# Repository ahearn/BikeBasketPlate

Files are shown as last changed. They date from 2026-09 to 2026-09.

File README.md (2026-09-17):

# Bike Basket Adapter Plate

OpenSCAD model of the basket-side mounting plate for a Bontrager Interchange
handlebar basket. This is the plate that screws to the basket and clips onto
the bracket on the bike.

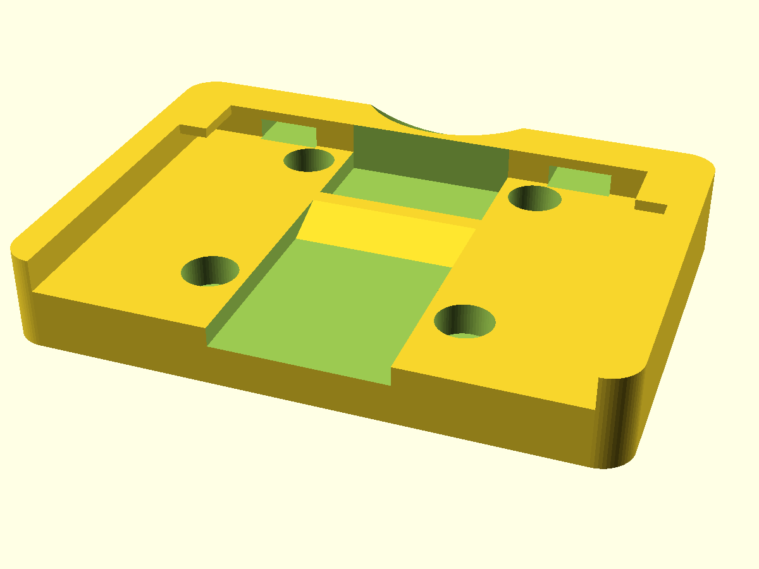
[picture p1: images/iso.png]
Isometric view


## What it fits

The [Bontrager Interchange Handlebar
Basket](https://www.trekbikes.com/us/en_US/equipment/bike-accessories/bike-baskets/bontrager-interchange-handlebar-basket/p/25614/).
The bike-side bracket carries Japanese and German patent numbers, a Sunny Wheel
Industrial licence notice and a 5 kg rating, so baskets sold under other brands
on the same licensed mount may use this geometry too.

This replaces the basket plate only. The bracket on the bike and its spring
lever need to be intact.

Dimensions came off one plate. Check them against yours before printing.

## How it mounts

Four countersunk screws hold the plate to the basket. The basket then drops
onto the bike-side bracket: the bracket's tongue slides into the slot between
the wings and the plate floor, guided by the central channel, and the spring
lever rides up the ramped latch and drops in behind it.

To release, press the lever through the scoop in the top wall.

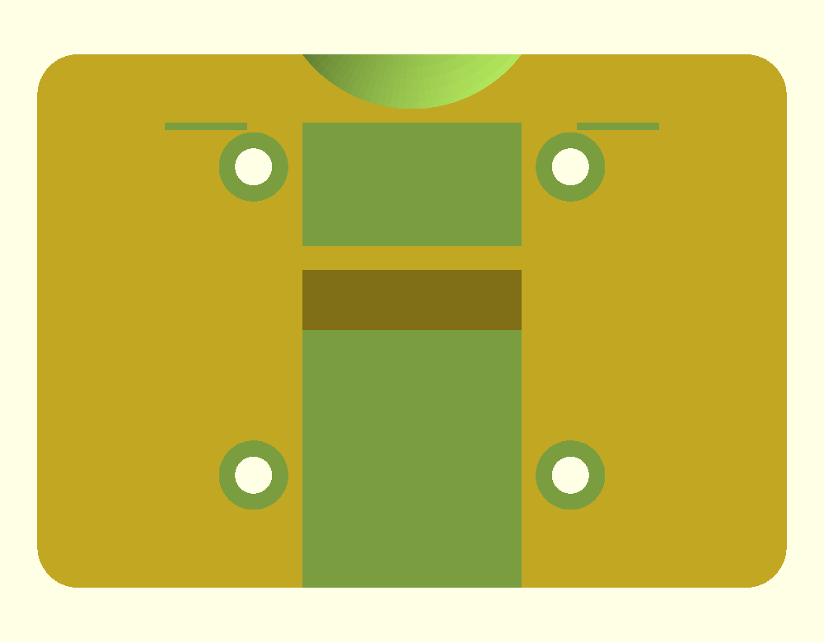
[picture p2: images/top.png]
Top view


## Dimensions

Heights are measured from the flat underside.

| Feature | Value |
|---|---|
| Overall | 109 × 77.7 mm |
| Main surface (screw-hole floor) | 11 mm |
| Channel floor | 7.4 mm |
| Perimeter wall / wing tops | 17 mm |
| Central channel width | 32 mm |
| Channel edge to side wall | 32.5 mm each side |
| Screw holes | 10.1 mm counterbore, 5.4 mm shaft, through |
| Screw hole centres | 46.1 mm across × 44.9 mm down |
| Latch | 8.8 mm ramp + 3.4 mm flat, top flush at 11 mm |
| Latch position | catch face 18 mm from the top wall |
| Wings | 21.6 mm long, 5.8 mm overhang, 2 mm thick |

The original plate is 105 mm wide. This one is 109 mm, which puts 2 mm of
clearance on each side wall and wing. Set `wall_relief = 0` for the original
width.

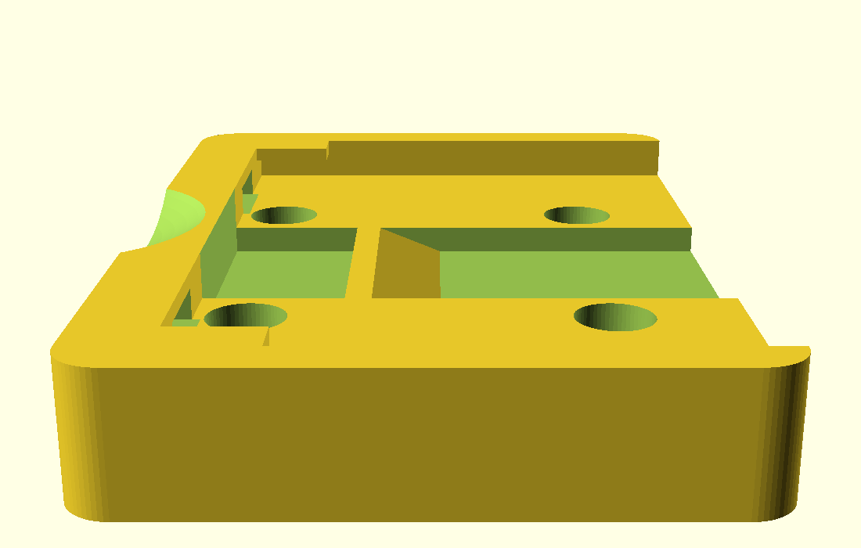
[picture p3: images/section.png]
Half section through the channel


## Building

Needs [OpenSCAD](https://openscad.org/). A built `basket_adapter_plate.stl` is
included. To regenerate it:

```
openscad -o basket_adapter_plate.stl basket_adapter_plate.scad
```

Every dimension is a named parameter at the top of the .scad file. A few are
marked `not measured` in the source — corner radius, top wall width, finger
scoop — and none of them affect how the plate latches.

## Printing

Print flat on the underside.

The wings cantilever 5.8 mm over a 4 mm gap and need support. The slots through
the top wall bridge 12 mm and print fine without.

PLA is fine for checking fit. Use PETG or ABS for something you'll actually
ride with. The mount is rated for 5 kg, and a printed plate won't match the
moulded original, so leave some margin.

## License

MIT

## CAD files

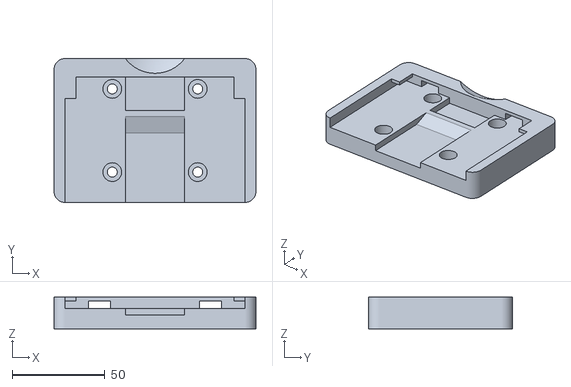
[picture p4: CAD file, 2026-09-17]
basket_adapter_plate.stl
109.0 x 77.7 x 17.0

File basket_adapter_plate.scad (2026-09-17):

// Basket adapter plate — bolts to the basket (4 screws), clips onto the
// bike-mounted bracket. Center channel carries a door-catch style latch bump;
// hook tabs on the side rims engage the bracket.
//
// All Z heights are absolute, measured from the flat underside of the part.

// ---- Overall plate ----
plate_w_nominal = 105;   // as measured on the original
wall_relief     = 2.0;   // side walls pushed out for fit; wings follow them
plate_w  = plate_w_nominal + 2 * wall_relief;
plate_h  = 77.7;
corner_r = 6;      // not measured

// ---- Z datums (underside = 0) ----
main_surface_z  = 11;    // flat area around the screw holes
channel_floor_z = 7.4;   // recessed groove floor
rim_z           = 17;    // top of raised perimeter wall
latch_top_z     = 11;    // flush with main surface
tab_top_z       = 17;    // flush with rim

// ---- Center channel (open through the bottom edge) ----
channel_w = 32;

// ---- Perimeter rim (top, left, right only — bottom edge is open) ----
channel_to_wall = 30.5 + wall_relief;  // measured 30.5, plus the fit relief
rim_w_side = plate_w / 2 - channel_w / 2 - channel_to_wall;
rim_w_top  = 10;         // not measured

// ---- Latch bump: ramp faces the bottom edge so the lever rides up it ----
latch_ramp_run = 8.8;   // slope run along the channel
latch_flat_run = 3.4;   // flat top run along the channel
latch_w        = channel_w;
latch_to_top_wall = 18;  // catch face to the top wall's inner face

// ---- Screw holes (countersunk, through) ----
cbore_d     = 10.1;
cbore_depth = 5.8;
shaft_d     = 5.4;
screw_h_gap = 36;      // edge-to-edge
screw_v_gap = 34.8;    // edge-to-edge
screw_h_pitch = screw_h_gap + cbore_d;  // gaps were measured between counterbore rims
screw_v_pitch = screw_v_gap + cbore_d;

// ---- Hook wings: overhang inward off the side rims, forming a slot with the
//      main surface that the bike bracket's tongue slides into ----
tab_len       = 21.6;  // along the side edge, starting at the top edge
tab_overhang  = 5.8;   // inward past the rim's inner face
tab_thickness = 2;

// ---- Finger scoop: dish in the top rim above the channel, so a finger can
//      reach the bike-side release button. Cosmetic, approximated as a sphere.
scoop_width     = 40;  // across at rim level
scoop_depth     = 6;   // how far below the rim top the sphere bottoms out
scoop_edge_wall = 2;   // wall kept between the scoop and the channel opening

// ---- Rectangular slots through the top perimeter wall, one each side of the
//      channel, sitting on the recessed floor.
slot_w   = 12;
slot_h   = 4;
slot_gap = 8;   // channel edge to the slot's near edge

$fn = 60;

module rounded_rect(w, h, r) {
    hull()
        for (x = [-1, 1], y = [-1, 1])
            translate([x * (w / 2 - r), y * (h / 2 - r)])
                circle(r = r);
}

module body() {
    linear_extrude(height = main_surface_z)
        rounded_rect(plate_w, plate_h, corner_r);
}

module rim() {
    wall_h = rim_z - main_surface_z;
    translate([0, 0, main_surface_z])
        linear_extrude(height = wall_h)
            difference() {
                rounded_rect(plate_w, plate_h, corner_r);
                // void shifted down so the rim covers top/left/right but not bottom
                translate([0, -rim_w_top])
                    square([plate_w - 2 * rim_w_side, plate_h], center = true);
            }
}

module channel_cut() {
    depth = main_surface_z - channel_floor_z;
    translate([-channel_w / 2, -plate_h / 2 - 1, channel_floor_z])
        cube([channel_w, plate_h + 1 - rim_w_top, rim_z - channel_floor_z + 1]);
}

module latch() {
    rise = latch_top_z - channel_floor_z;
    y_catch = plate_h / 2 - rim_w_top - latch_to_top_wall;
    y0 = y_catch - (latch_ramp_run + latch_flat_run);
    translate([0, y0, channel_floor_z])
        rotate([90, 0, 90])
            linear_extrude(height = latch_w, center = true)
                polygon([[0, 0],
                         [latch_ramp_run, rise],
                         [latch_ramp_run + latch_flat_run, rise],
                         [latch_ramp_run + latch_flat_run, 0]]);
}

module finger_scoop() {
    // sphere sized so it cuts scoop_width across at rim_z and bottoms out
    // scoop_depth below it
    r = (pow(scoop_width / 2, 2) + pow(scoop_depth, 2)) / (2 * scoop_depth);
    // pushed out past the top edge so a scoop_edge_wall-thick rib survives
    // between the scoop and the channel opening
    y = plate_h / 2 - rim_w_top + scoop_edge_wall + scoop_width / 2;
    translate([0, y, rim_z + r - scoop_depth])
        sphere(r = r, $fn = 120);
}

module wall_slots() {
    z0 = main_surface_z;
    for (side = [-1, 1]) {
        x0 = (side > 0) ? channel_w / 2 + slot_gap
                        : -channel_w / 2 - slot_gap - slot_w;
        translate([x0, plate_h / 2 - rim_w_top - 1, z0])
            cube([slot_w, rim_w_top + 2, slot_h]);
    }
}

module screw_hole() {
    translate([0, 0, main_surface_z - cbore_depth])
        cylinder(d = cbore_d, h = cbore_depth + 1);
    translate([0, 0, -1])
        cylinder(d = shaft_d, h = main_surface_z + 2);
}

module screw_holes() {
    for (x = [-1, 1], y = [-1, 1])
        translate([x * screw_h_pitch / 2, y * screw_v_pitch / 2, 0])
            screw_hole();
}

module hook_tab(side) {
    inner_face = plate_w / 2 - rim_w_side;
    x0 = (side > 0) ? inner_face - tab_overhang : -inner_face;
    translate([x0, plate_h / 2 - tab_len, tab_top_z - tab_thickness])
        cube([tab_overhang, tab_len, tab_thickness]);
}

module basket_adapter_plate() {
    union() {
        difference() {
            union() {
                body();
                rim();
                hook_tab(1);
                hook_tab(-1);
            }
            channel_cut();
            screw_holes();
            finger_scoop();
            wall_slots();
        }
        latch();  // added after the cut, since it lives inside the channel
    }
}

basket_adapter_plate();

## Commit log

2026-09-16 Add parametric OpenSCAD model for bike basket adapter plate
    Replacement for the broken basket-side plate of a Sunny Wheel quick-release
    basket mount. Reverse-engineered from caliper measurements of the original,
    with all heights referenced to the part's flat underside so the profile stays
    consistent: channel floor 7.4, main surface 11, rim and wing tops 17.
    Features: 105x77.7 tray with rim on three sides, center channel open through
    the bottom edge, door-catch latch (8.8 ramp + 3.4 flat) 45.5 from the bottom
    edge, inward-overhanging wings forming the bracket capture slot, four
    countersunk through-holes, finger scoop, and slots through the top wall.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
    [basket_adapter_plate.scad, basket_adapter_plate.stl]
2026-09-16 Correct side rim width from measured channel-to-wall spacing
    Test print fit well, but the floor either side of the channel measured
    30.5mm against the model's 26.5 — the 10mm side rim was a guess and is
    actually 6mm (6 + 30.5 + 32 + 30.5 + 6 = 105).
    Drives rim width from the measured spacing rather than hardcoding it, and
    splits side/top rim widths since only the sides are measured. The wings
    follow the side wall outward, which also widens the rib between each wall
    slot and its wing from a barely-printable 0.7mm to 4.7mm.
    [basket_adapter_plate.scad, basket_adapter_plate.stl]
2026-09-16 Relieve side wall and wing fit by 0.5mm per side
    Test print seated but the wings pinched the mount plate and the side walls
    were snug against it. Pushes both side walls out 0.5mm, which the wings
    follow automatically since their position derives from the wall inner face
    — opening the clear span between wings from 81.4 to 82.4mm.
    Keeps the 6mm wall thickness rather than thinning it, so the plate grows to
    106mm overall. Nothing constrains the outer width, and the relief is a named
    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
    [basket_adapter_plate.scad, basket_adapter_plate.stl]
2026-09-16 Add README with rendered views
    Documents what the part fits, how the latch and wing mechanism engages, and
    the measured dimensions, so someone with the same broken mount can check it
    against their own part before printing.
    Calls out which parameters are photograph estimates rather than measured,
    and notes that a printed plate carries the basket's full load and should not
    be assumed to match the injection-moulded original's strength.
2026-09-16 Identify the source basket in the README
    Names the Bontrager Interchange Handlebar Basket and links the product page,
    so someone can confirm they have the same mount before printing. Notes that
    the bracket is built on a licensed Sunny Wheel mount, since baskets sold under
    other brands may share the geometry.
2026-09-16 Trim the README
    Drop the development history and tighten the prose.
2026-09-16 Widen side clearance to 1 mm per side
    Plate goes to 107 mm. Re-exported the STL and renders.
    [basket_adapter_plate.scad, basket_adapter_plate.stl]
2026-09-17 Move the latch 8 mm down the channel
    Catch face now sits 18 mm clear of the top wall instead of 10. Anchors the
    latch to the top wall rather than the bottom edge, since that is the surface
    the clearance is measured against.
    [basket_adapter_plate.scad, basket_adapter_plate.stl]
2026-09-17 Widen side clearance to 2 mm per side
    Wings were still gripping. Plate goes to 109 mm.
    [basket_adapter_plate.scad, basket_adapter_plate.stl]
